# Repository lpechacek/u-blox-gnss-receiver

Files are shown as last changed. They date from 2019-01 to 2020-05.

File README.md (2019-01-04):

# u-blox-gnss-receiver
Document about design of a Bluetooth GNSS receiver.

Keywords: GNSS, Bluetooth, Android, GPS, GLONASS, BeiDou, Galileo



This work is licensed under a [Creative Commons Attribution 4.0 International License](http://creativecommons.org/licenses/by/4.0/).

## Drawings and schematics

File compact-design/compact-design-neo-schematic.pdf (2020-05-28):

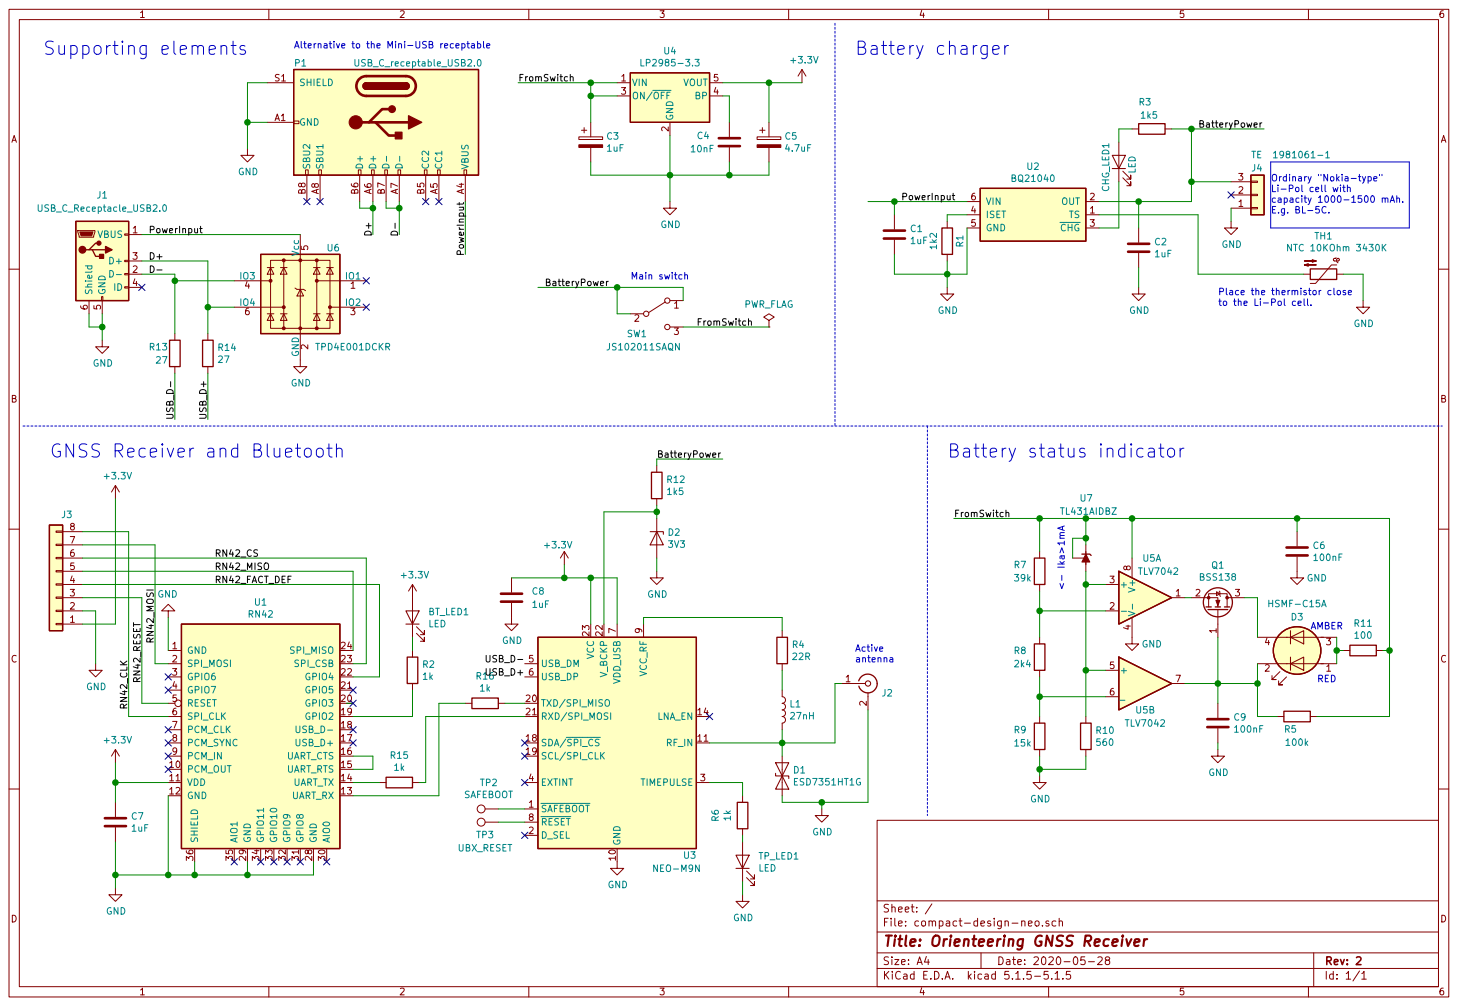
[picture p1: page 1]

Alternative to the Mini-USB receptable

to the Li-Pol cell. <- Ika>1mA

AMBER GNSS Receiver and Bluetooth

Id: 1/1 Title: Orienteering GNSS Receiver

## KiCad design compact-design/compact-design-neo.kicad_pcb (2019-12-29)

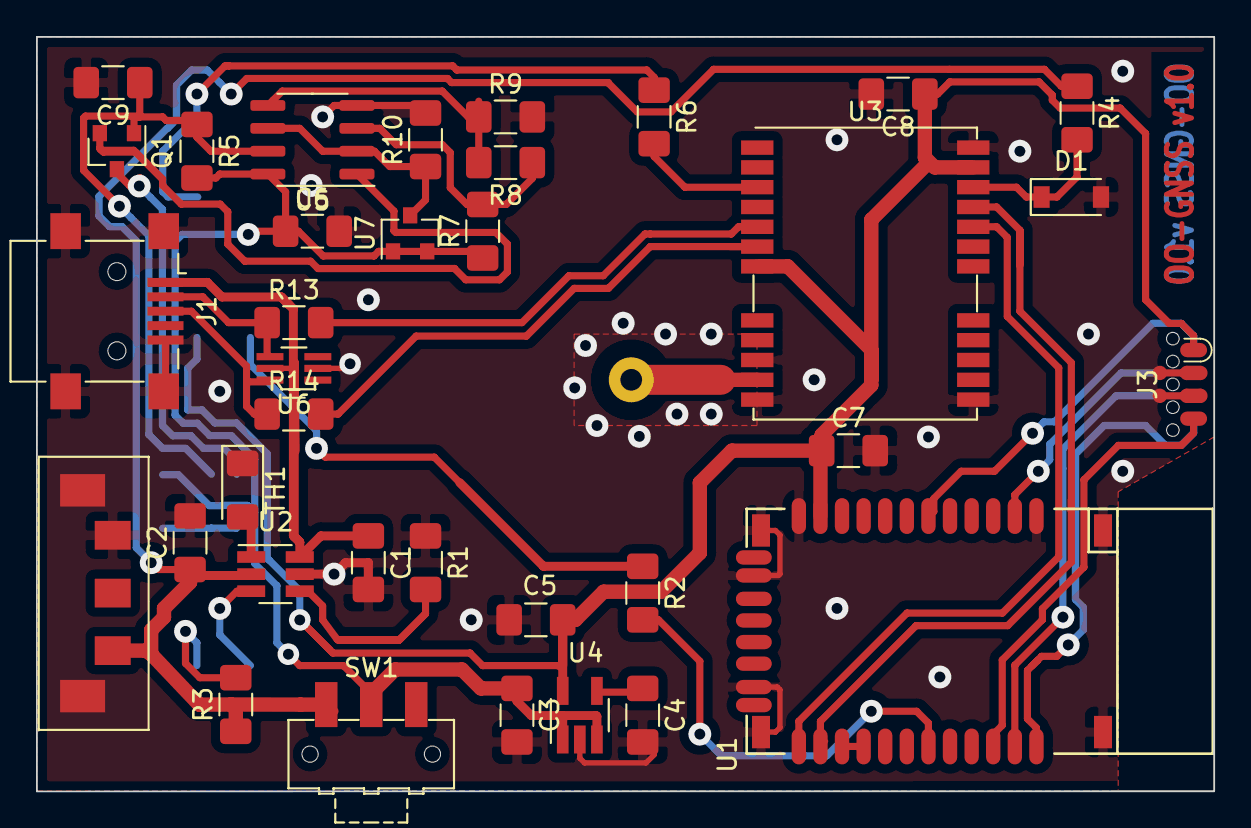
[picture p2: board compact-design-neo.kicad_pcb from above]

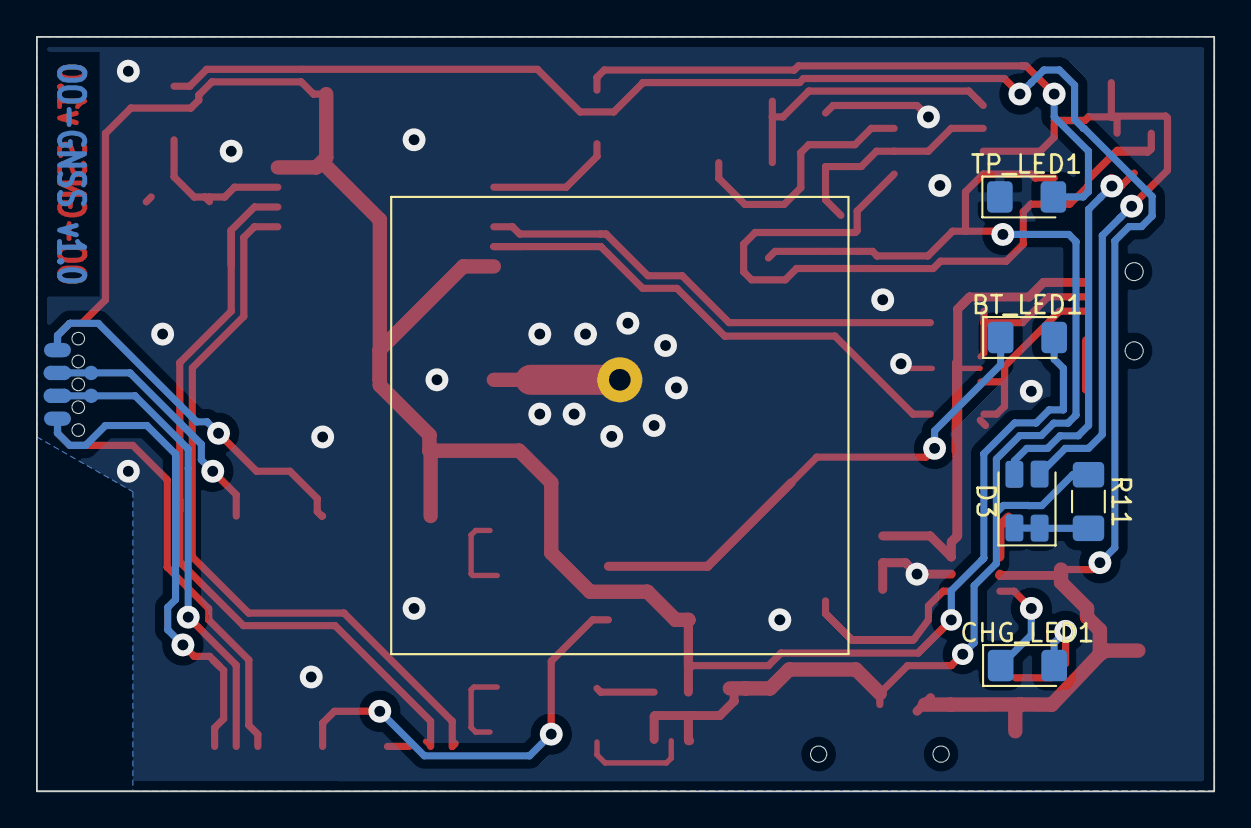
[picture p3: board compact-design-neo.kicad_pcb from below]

Board: 2 copper layers, 65.4 x 41.9 mm, 41 parts (6 on the bottom side), 35 nets.

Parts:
AE1: Taoglas CGPP.25.4.E.02; gnss-patch-25x25
BT_LED1: LED; LED_1206_3216Metric_Pad1.42x1.75mm_HandSolder
C1, C2, C3: 1uF; C_1206_3216Metric_Pad1.42x1.75mm_HandSolder
C4: 10nF; C_1206_3216Metric_Pad1.42x1.75mm_HandSolder
C5: 4.7uF; C_1206_3216Metric_Pad1.42x1.75mm_HandSolder
C6, C7, C8, C9: 100nF; C_1206_3216Metric_Pad1.42x1.75mm_HandSolder
CHG_LED1: LED; LED_1206_3216Metric_Pad1.42x1.75mm_HandSolder
D1: 3V3; D_SOD-123
D3: HSMF-C15A; LED_DUAL_1210_3225Metric_Pad1x1.5mm_HandSolder
J1: USB_C_Receptacle_USB2.0; USB_Mini-B_Lumberg_2486_01_Horizontal
J3: SOICbite; SOIC_clipProgSmall
J4: TE 1981061-1; connector-TE_1981061-1
Q1: BSS138; SOT-23
R1: 1k2; R_1206_3216Metric_Pad1.42x1.75mm_HandSolder
R2, R6: 1k; R_1206_3216Metric_Pad1.42x1.75mm_HandSolder
R3: 1k5; R_1206_3216Metric_Pad1.42x1.75mm_HandSolder
R4: 64k; R_1206_3216Metric_Pad1.42x1.75mm_HandSolder
R5: 100k; R_1206_3216Metric_Pad1.42x1.75mm_HandSolder
R7: 39k; R_1206_3216Metric_Pad1.42x1.75mm_HandSolder
R8: 2k4; R_1206_3216Metric_Pad1.42x1.75mm_HandSolder
R9: 15k; R_1206_3216Metric_Pad1.42x1.75mm_HandSolder
R10: 560; R_1206_3216Metric_Pad1.42x1.75mm_HandSolder
R11: 100; R_1206_3216Metric_Pad1.42x1.75mm_HandSolder
R13, R14: 27; R_1206_3216Metric_Pad1.42x1.75mm_HandSolder
SW1: JS102011SAQN; SW_SPDT_CK-JS102011SAQN
TH1: Thermistor_NTC; D_1206_3216Metric_Pad1.42x1.75mm_HandSolder
TP_LED1: LED; LED_1206_3216Metric_Pad1.42x1.75mm_HandSolder
U1: RN42
U2: BQ21040; SOT-23-6_Handsoldering
U3: NEO-M8N; ublox_NEO
U4: LP2985-3.3; SOT-23-5_HandSoldering
U5: LM293; SOIC-8_3.9x4.9mm_P1.27mm
U6: TPD4E001DCKR; SOT-363_SC-70-6_Handsoldering
U7: TL431AIDBZ; SOT-23

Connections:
+3V3: BT_LED1.2, C5.1, C7.1, C8.1, J3.1, U1.11, U3.7, U3.23, U4.5
/BatteryPower: C2.1, J4.1, R3.1, R4.1, SW1.1, U2.2
/D+: J1.3, R14.1, U6.6
/D-: J1.2, R13.1, U6.4
/FromSwitch: C3.1, C6.1, R5.2, R7.1, R11.1, SW1.2, U4.1, U4.3, U5.8, U7.1, U7.2
/PowerInput: C1.1, J1.1, U2.6, U6.5
/RN42_CLK: J3.8, U1.6
/RN42_CS: J3.6, U1.23
/RN42_FACT_DEF: J3.4, U1.22
/RN42_MISO: J3.5, U1.24
/RN42_MOSI: J3.7, U1.2
/USB_D+: R14.2, U3.6
/USB_D-: R13.2, U3.5
GND: C1.2, C2.2, C3.2, C4.2, C5.2, C6.2, C7.2, C8.2, C9.2, D1.2, J1.5, J1.6, J3.2, J3.3, J4.3, R1.1, R9.2, R10.2, TH1.1, TP_LED1.1, U1.1, U1.12, U1.28, U1.29, U1.36, U2.5, U3.10, U3.12, U3.13, U3.24, U4.2, U5.4, U6.2
unnamed: AE1.1, U3.11
unnamed: BT_LED1.1, R2.1
unnamed: C4.1, U4.4
unnamed: C9.1, D3.4, Q1.1, R5.1, U5.7
unnamed: CHG_LED1.1, U2.3
unnamed: CHG_LED1.2, R3.2
unnamed: D1.1, R4.2, U3.22
unnamed: D3.1, D3.3, R11.2
unnamed: D3.2, Q1.3
unnamed: Q1.2, U5.1
unnamed: R1.2, U2.4
unnamed: R2.2, U1.19
unnamed: R6.1, TP_LED1.2
unnamed: R6.2, U3.3
unnamed: R7.2, R8.1, U5.3
unnamed: R8.2, R9.1, U5.5
unnamed: R10.1, U5.2, U5.6, U7.3
unnamed: TH1.2, U2.1
unnamed: U1.13, U3.20
unnamed: U1.14, U3.21
unnamed: U1.15, U1.16

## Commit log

2019-12-29 Compact receiver design
    Basically the same design again with charger circuit, voltage regulator and
    battery charge indicator on one board.
    [compact-design-neo.kicad_pcb, compact-design-neo.sch]
2020-01-31 u-blox-gnss-receiver: Add Lessons Learned
    Document lessons learned about power bank selection and the misbehavior of the
    on-board memory backup battery.
2020-05-28 Compact receiver design: Updated schematics
    This schematic embodies the lessons learned from the first prorotype. It
    eliminates a few apparent bugs and switches to an actie antenna. In
    reality the Bluetooth module generated enough noise to completely block
    GNSS reception. Using a detachable active antenna with an additional SAW
    filter solves the problem.
    [compact-design-neo.sch]

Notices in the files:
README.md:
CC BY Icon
